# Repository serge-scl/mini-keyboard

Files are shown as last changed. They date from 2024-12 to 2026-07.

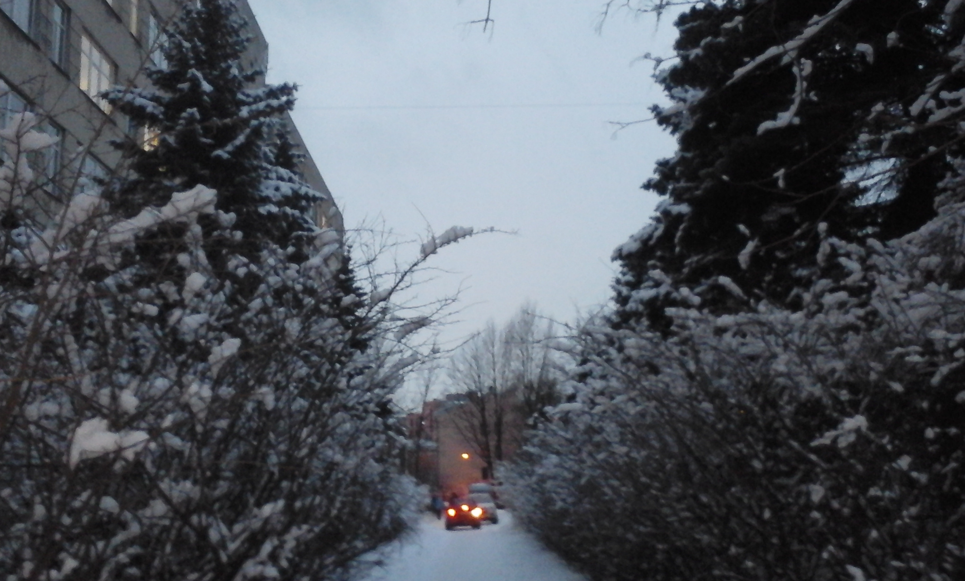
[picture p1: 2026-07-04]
media/winta_light.jpg

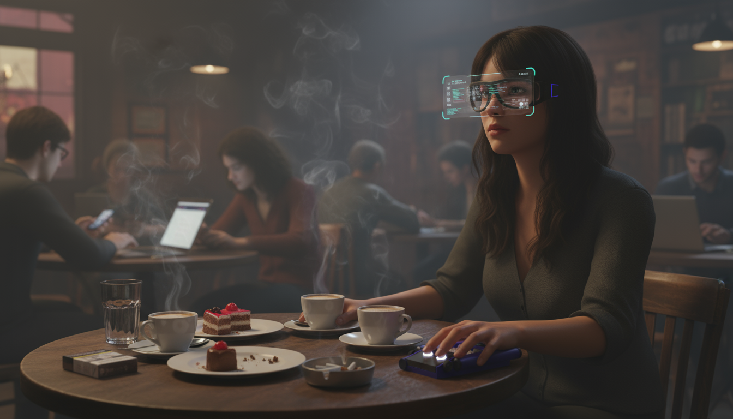
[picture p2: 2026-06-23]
media/cafe.png

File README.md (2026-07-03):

# Mouse Keyboard Pyramids (MKP)

Hybrid mouse + keyboard using pyramid-shaped touch/tilt keys. MKP combines capacitive touch, tilt sensing, and small-form HID firmware to provide an alternative input device for typing and pointing.

## Features
- Pyramid-shaped keys: touch shows cursor location; tilt selects symbols/directions.
- Position sensing: MPR121 capacitive touch controller (per-pyramid address).
- Tilt sensing: magnet-mounted mesh + Hall sensors detect X/Y tilt.
- Keyboard: 5×3 matrix (with diodes) + two dedicated joystick inputs.
- Pointing: optional optical sensor (PMW3360) and two side scroll wheels (one per side).
- Modular hardware: removable side modules with 4×AA battery holders and PCBs; LED backlight PCB under keyboard.
- Assembly designed for minimal tools; partly tool-free disassembly.
- Wireless option: Raspberry Pi Pico (or Pico W for Wi‑Fi); CircuitPython with Adafruit libraries and HID support.

## Software & Files
- CircuitPython code and example text editor included in repo root (Python).
- FreeCAD (part/assembly) models and KiCad schematics/PCB in respective folders.
- Datasheet folder contains BOM, diagrams, and images.

## License
CC‑BY‑4.0

## Contact
Serge Sokolov — sergesclv@gmail.com / sergesclv3@protonmail.com

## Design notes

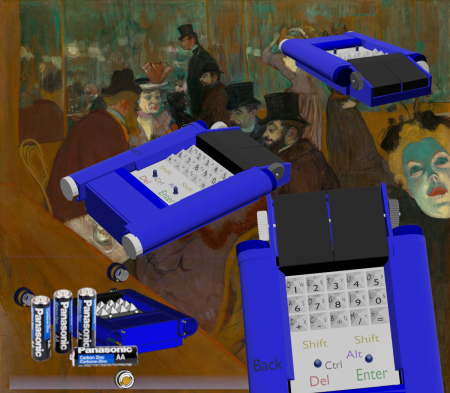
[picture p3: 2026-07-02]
media/mkps_290626.png

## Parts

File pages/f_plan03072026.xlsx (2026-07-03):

 |  |  | Financial plan
 |  | ncludes sponsorship support for open source, non-profit development
 |  | since the plan also includes starting a company
 |  | Funds from sponsorship support will be used for travel, accommodation, and opening the company itself in a location where this is possible.
 |  |  | final amounts
 |  | total investment amount |  |  | $ | 420000
 |  | planned batch of devices |  |  | unit | 100000
 |  | total sales revenue |  |  | $ | 19900000
 |  | margin |  |  | $ | 1990000
 |  | I apologize for my literary style (but I am also offering something that is the same writing instrument as a pen, ballpoint pen, or typewriter).
 |  | The batch of 100,000 pieces considered here is naturally not the entire consumer niche of my device.
 |  | This is only the first story about the initial stage of all the work. And it has its own separate plot.
 |  | This is an assumption, and like any assumption it must end where everything seems reliable for now.
 |  |  | The stage of burning financial resources.
 | support from sponsors |  |  | 6500 | 8100
 |  |  |  |  | Revenue item $ | Expense item $ | $ unit | quantity | time
 |  | flight tickets |  |  |  | 1200 | 600 | 2
 |  | accommodation |  |  |  | 1400 | 700 | 2 | 7 | days
 |  | daily expenses |  |  |  | 2000 | 1000 | 2 | 7 | days
 |  | open a company
 |  |  | LLC |  |  | 1900
 |  |  | C-Corp |  |  | 3500
 | investments in newly opened company
 |  |  |  | LLC | 413500
 |  |  |  | C-Corp | 411900
 |  | company office |  |  |  | 61200 | 1700 | 4 | 9 | months
 |  | equipment |  |  |  | 40000 | 10000 | 4
 |  | pre-production units of the device |  |  |  | 57820 | 5782 | 10
 | hiring |  |  |  |  |  | salary | vacancies
 |  | designer |  |  |  | 90000 | 60000 | 2 | 9 | months
 |  | PR menager |  |  |  | 15000 | 60000 | 1 | 3 | months
 |  | electronics development |  |  |  | 30000 | 60000 | 1 | 6 | months
 |  | firmware creation |  |  |  | 30000 | 60000 | 1 | 6 | months
 |  | sum |  |  |  |  |  | 5
 | website creation
 |  | server |  |  |  | 2000
 |  | domain registration |  |  |  | 20
 |  | web development |  |  |  | 10000
 |  | website administration |  |  |  | 30000
 |  | text editor project |  |  |  | 5000
 |  | sum |  |  |  | 371040
 |  | balance on accounts
 |  |  |  | LLC | 42460
 |  |  |  | C-Corp | 40860
 | cost estimate
 |  | assembly operation |  |  | quantity | seconds | just seconds
 |  |  | 1 |  | 6 | 10 | 60
 |  |  | 2 |  | 17 | 10 | 170
 |  |  | 3 |  | 17 | 15 | 255
 |  |  | 4 |  | 3 | 10 | 30
 |  |  | 5 |  | 3 | 10 | 30
 |  |  | 6 |  | 8 | 15 | 120
 |  |  | 7 |  | 3 | 15 | 45
 |  |  | 8 |  | 2 | 10 | 20
 |  |  | 9 |  | 2 | 10 | 20
 |  |  | 10 |  | 1 | 15 | 15
 |  |  | 11 |  | 1 | 10 | 10
 |  |  | 12 |  | 2 | 10 | 20
 |  |  | 13 |  | 2 | 15 | 30
 |  |  | 14 |  | 1 | 10 | 10
 |  |  | 15 |  | 18 | 10 | 180
 |  |  | 16 |  | 6 | 10 | 60
 |  |  | 17 |  | 1 | 10 | 10
 |  |  | 18 |  | 5 | 10 | 50
 |  |  | 19 |  | 4 | 10 | 40
 |  |  | 20 |  | 1 | 15 | 15
 |  |  | 21 |  | 4 | 10 | 40
 |  |  |  |  | time
 | working days per year |  |  |  | 249
 | hours in a working day |  |  |  | 8
 | hours per assembly day |  |  |  | 5
 | working minutes per year |  |  |  | 119520
 | assembly minutes per year |  |  |  | 74700
 |  | assembly of one device
 | seconds |  |  |  | 1230
 | minutes |  |  |  | 20.5
 | hours |  |  |  | 0.3416666667
 | daily norm |  |  |  | 15
 | assembly of the entire batch of devices
 | Man-hours |  |  |  | 3417
 | man-days |  |  |  | 683
 | In the business plan, I explained in more detail why I only consider five hours a day to be allocated to assembly work.
 | In short, the remaining three hours are a preparatory period.
 | period of work with the participation of all teams of assemblers
 |  |  |  |  | 68.3
 |  |  | price |  | $
 | rent of industrial premises |  |  |  | 4320
 | electricity bills |  |  |  | 266400
 | price of conditional working minute of assembler |  |  |  | 0.6157965194
 | cost of assembly of one product
 | cost of the assembler's time |  |  |  | 13
 | other salaries, rent and electricity |  |  |  | 17
 | overhead costs 100% |  |  |  | 30
 | supply of plastic injection molding components |  |  |  | 104
 | springs and fasteners |  |  |  | 2
 | motherboard |  |  |  | 12
 | additional electronic components |  |  |  | 5
 | trading platform commission |  |  |  | 9.95 | 5 | %
 | transaction commission |  |  |  | 5.97 | 3 | %
 | sum |  |  |  | 198.92
 |  |  | Crowdfunding |  | Revenue item $ | Expense item $ | $ unit | quantity
 | creating an advertising video |  |  |  |  | 4000
 | other advertising and promotion costs |  |  |  |  | 10000
 | time |  |  |  |  |  |  | 2 | month
 | required funds and quantity to start work |  |  |  | 1990000 |  | 199 | 10000
 | hiring the required employees
 |  | Head of Supply Department |  |  |  | 120000 | 120000 | 1
 |  | production manager |  |  |  | 120000 | 120000 | 1
 |  | assembly line workers |  | random |  | 460000 | 46000 | 10
 |  | repairmans |  |  |  | 60000 | 30000 | 2
 |  | tester |  |  |  | 50000 | 50000 | 1
 |  |  |  |  |  |  |  | 5
 |  | pre-launch costs
 | prepayment for ordering press molds |  |  |  |  | 360000 | 60000 | 20 | 0.3
 | advance payment for the first batch of parts |  |  |  |  | 312000 | 104 | 10000 | 0.3
 | electronic components |  |  |  |  | 170000 | 17 | 10000 | 1
 | payment for initial production downtime |  |  | day
 |  |  |  | 1 |  | 4469
 |  |  | week | 5 |  | 22345
 |  |  | month | 22 |  | 98318
 |  |  | possible term | 50 |  | 223450
 |  |  |  |  |  | 1190582
 |  |  |  | Start Working
 | workers | daily profit |  | break-even point
 | in assembly | $ |  | weeks | with downtime
 | 9 | 3150 |  | 24 | 34
 | 10 | 3880 |  | 19.6 | 29.8
 | 11 | 4663 |  | 16.2 | 26.6
 | 12 | 5446 |  | 14 | 24.6
 | 13 | 6177 |  | 12.2 | 23
 | 14 | 6960 |  | 10.8 | 21.8
 | 15 | 7743 |  | 9.8 | 21
 | 16 | 8473 |  | 9 | 20.4
 | 17 | 9256 |  | 8.2 | 19.8
 | 18 | 9987 |  | 7.6 | 19.4
 | 19 | 10770 |  | 7 | 19
 | 20 | 11552 |  | 6.6 | 18.8
 | 21 | 12283 |  | 6.2 | 18.6
 | 22 | 13066 |  | 5.8 | 18.4
 | 23 | 13849 |  | 5.4 | 18.2
 | 24 | 14579 |  | 5.2 | 18.2
 | 25 | 15362 |  | 5 | 18.2
 | 26 | 16093 |  | 4.8 | 18.2
 | 27 | 16876 |  | 4.4 | 18
 | 28 | 17659 |  | 4.2 | 18
 | 29 | 18389 |  | 4.2 | 18.2
 | The advantage of a large team of assemblers seems obvious
 | if we don't have to take time delays into account
 | These delays are related to the hiring of new employees and their training
 | I don't think I'll be able to hire more than one new employee a day
 | When I added this amendment to the general downtime period, I got the result that there were no advantages in terms of time
 | Therefore, a large team is not a good solution to the problem of deadlines and product development.
 |  | total number | all time from rise of funds |  | Rise+work | working
 |  | employees | year | month | months | months
 |  | 10
 |  | 19 | 1.38 | 16.5 | 10.5 | 8.5
 |  | 20 | 1.29 | 15.45 | 9.45 | 7.45
 |  | 21 | 1.22 | 14.65 | 8.65 | 6.65
 |  | 22 | 1.18 | 14.15 | 8.15 | 6.15
 |  | 23 | 1.15 | 13.75 | 7.75 | 5.75
 |  | 14 | 1.12 | 13.45 | 7.45 | 5.45
 |  | 25 | 1.1 | 13.25 | 7.25 | 5.25
 |  | 26 | 1.09 | 13.1 | 7.1 | 5.1
 |  | 17 | 1.08 | 12.95 | 6.95 | 4.95
 |  | 28 | 1.07 | 12.85 | 6.85 | 4.85
 |  | 29 | 1.06 | 12.7 | 6.75 | 4.75
 |  | 30 | 1.06 | 12.7 | 6.7 | 4.7
 |  | 31 | 1.05 | 12.65 | 6.65 | 4.65
 |  | 32 | 1.05 | 12.6 | 6.6 | 4.6
 |  | 33 | 1.05 | 12.55 | 6.55 | 4.55
 |  | 34 | 1.05 | 12.55 | 6.55 | 4.55
 |  | 35 | 1.05 | 12.55 | 6.55 | 4.55
 |  | 36 | 1.05 | 12.55 | 6.55 | 4.55
 |  | 37 | 1.04 | 12.5 | 6.5 | 4.5
 |  | 38 | 1.04 | 12.5 | 6.5 | 4.5
 |  | 39 | 1.05 | 12.55 | 6.55 | 4.55
 |  |  | Timeline
 |  | First year
 | first quarter of the first year |  |  | second quarter of the first year |  |  | third quarter of the first year |  |  | fourth quarter of the first year
 | 1 month | 2 month | 3 month | 4 month | 5 month | 6 month | 7 month | 8 month | 9 month | 10 month | 11 month | 12 month
$ monthly | -8100 | -101200 | -62820 | -17020 | -24167 | -38167 | -24167 | -558487 | -53334 | -62917 | 598922 | 638529
$ total | -8100 | -109300 | -172120 | -189140 | -213307 | -251474 | -275641 | -834128 | -887462 | -950379 | -351457 | 287072
units of devices manufactured |  |  | 10 | 0 | 0 | 0 | 0 | 0 | 0 | 0 | 5175 | 6600
$ with | 411900 | -101200 | -62820 | -17020 | -24167 | -38167 | 1965833 | -558487 | -53334 | -62917 | -85117 | -85117
invest | 411900 | 310700 | 247880 | 230860 | 206693 | 168526 | 2134359 | 1575872 | 1522538 | 1459621 | 1374504 | 1289387
 | Serge Sokolov
 | app 18
 | 23 Lakhtinska
 | St. Petersburg 197136
 | Russia
 | Ph +79522711742
 | sergesclv@gmail.com
 | sergesclv3@protonmail.com
 | https://ru.linkedin.com/in/serge-sokolov-abb5319
 | https://x.com/SeregeSokolov
 | https://github.com/serge-scl/mini-keyboard
 | https://www.facebook.com/sergesclv/
 | https://maker.pro/raspberry-pi/projects/mouse-keyboard-pyramids

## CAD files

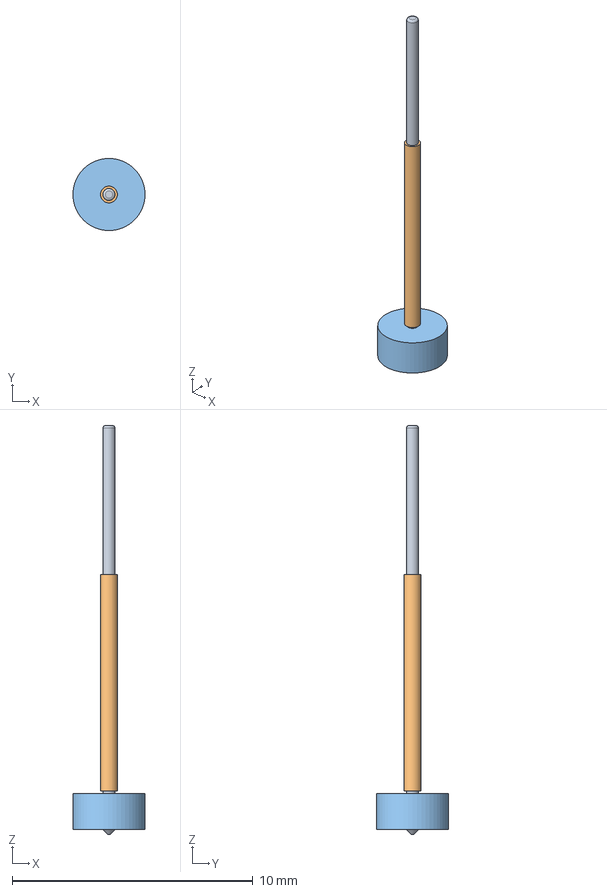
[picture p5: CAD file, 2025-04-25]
assembly/main_rod_arm.FCStd
3.00 x 3.00 x 17.0 mm
tilt_rod_core_001
rod shell top_001
rod_shell_foot_001

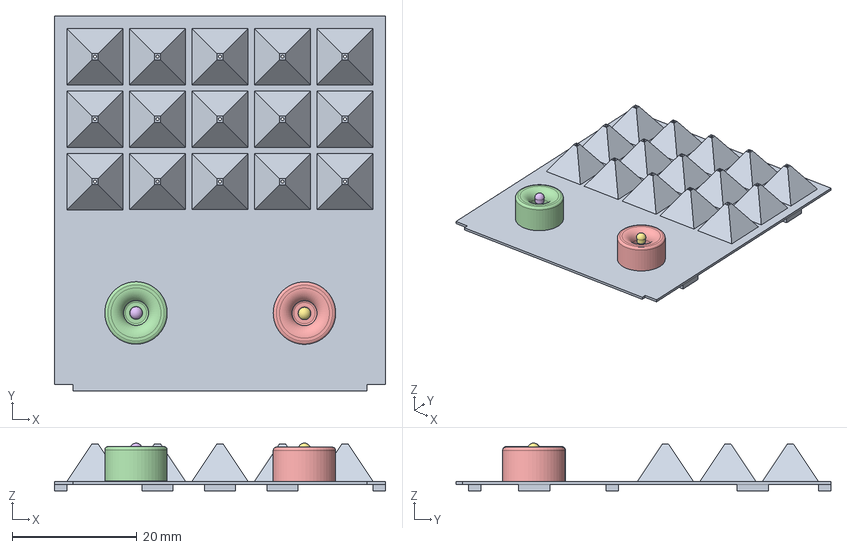
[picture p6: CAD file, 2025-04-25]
assembly/pyramids_asm.FCStd
53.0 x 60.0 x 7.65 mm
pyramids_001
steel_ring_001
steel_ring_002
Joystick_001
Joystick_002
boll_tilt_001
boll_tilt_002

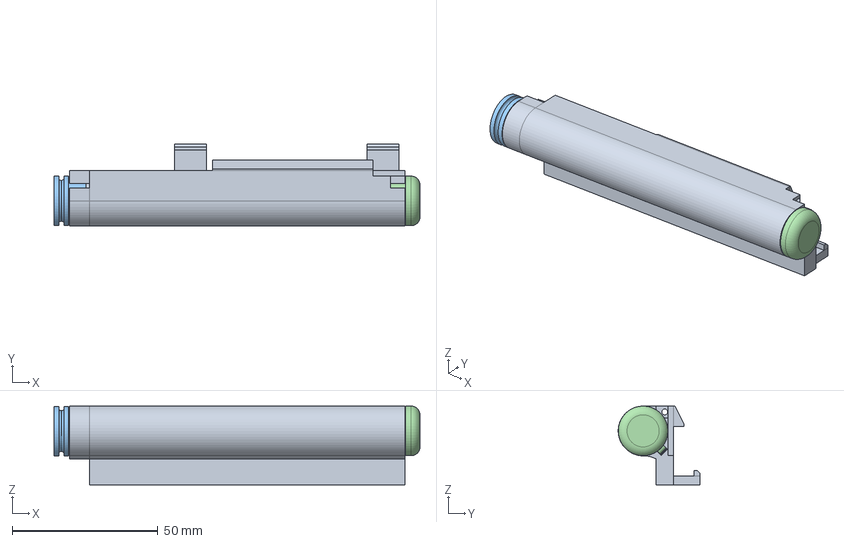
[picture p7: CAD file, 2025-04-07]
assembly/battery_wall_right_asm.FCStd
125.4 x 28.0 x 27.0 mm
battery_wall_right_001
conn_btr_asm_001
plug_back_conn_001
plug_front_conn_001

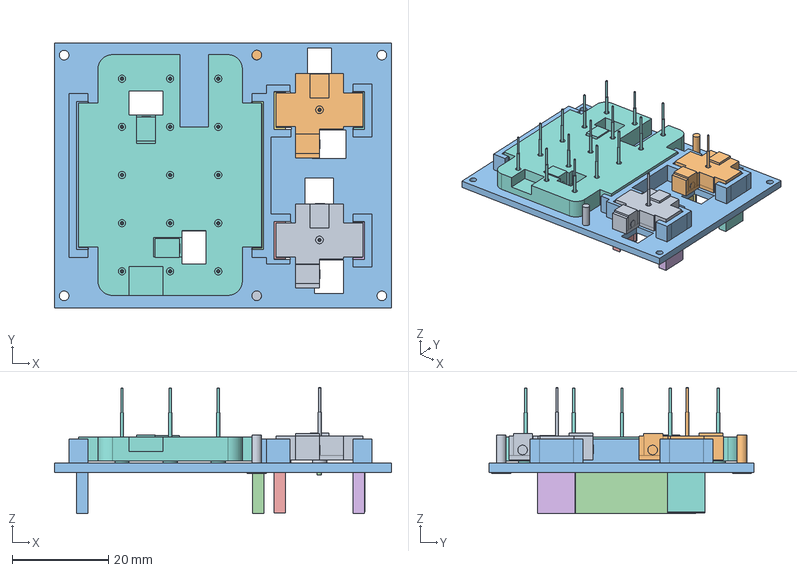
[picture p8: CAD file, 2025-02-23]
assembly/main module.FCStd
70.0 x 55.0 x 26.2 mm
mov_joystick_block_001
mov_joystick_block_002
touch_bottom2_001
pewter_foot1_002
pewter_foot1_003
pewter_foot2_002
pewter_foot2_003
mov_kb_block_002
fix_m_001
fix_m_002
kb_set_001
kb_set_002
joyst_set_001
joyst_set_002
joyst_set_003
joyst_set_004

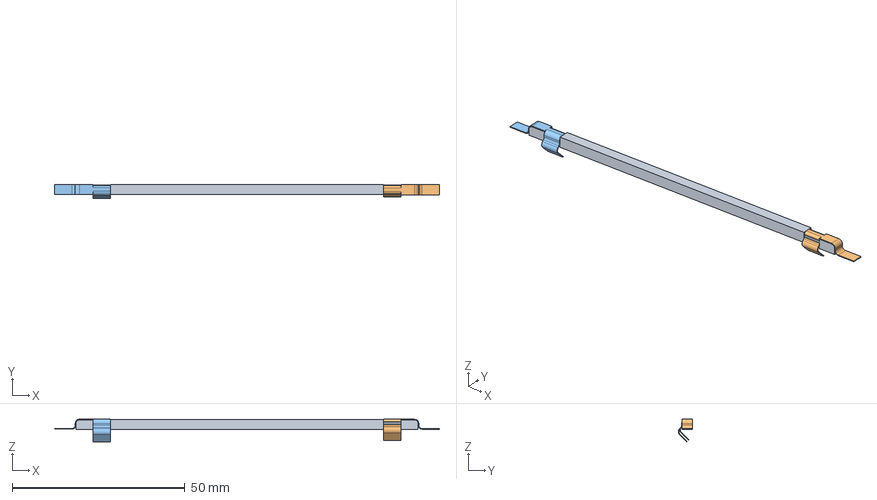
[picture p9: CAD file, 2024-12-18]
assembly/conn_btr_asm.FCStd
111.4 x 4.20 x 6.58 mm
wall_conn_btr_001
pin_conn_btr_001
pin_conn_btr2_001

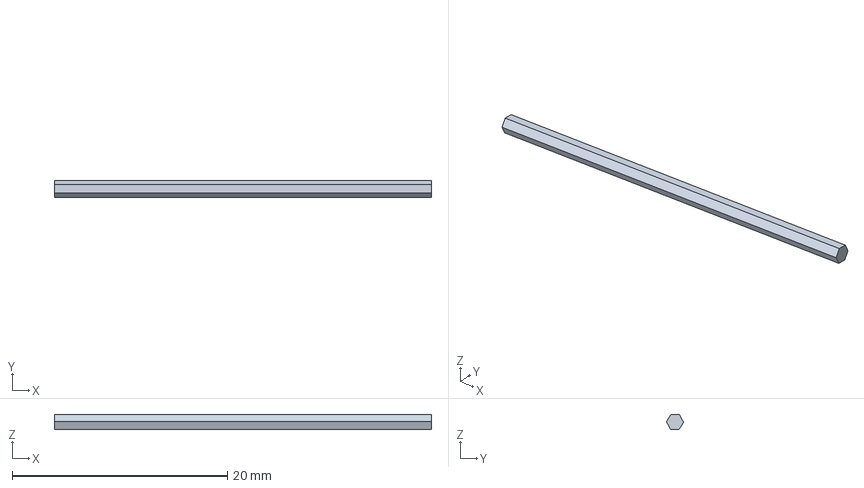
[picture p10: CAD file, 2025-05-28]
part/mouse_wheel_axis.FCStd
35.0 x 1.60 x 1.42 mm

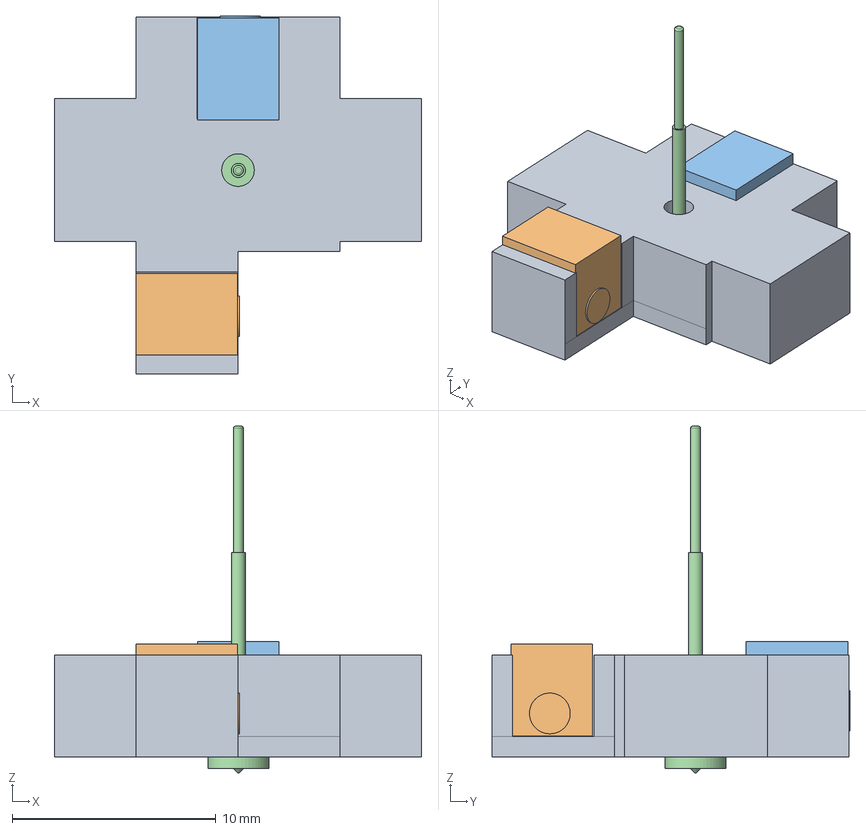
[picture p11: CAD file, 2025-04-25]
assembly/mov_joystick_block.FCStd
18.0 x 17.6 x 17.0 mm
sliding_cell_001
magnet_with_holder_001
magnet_with_holder_002
main_rod_arm_001

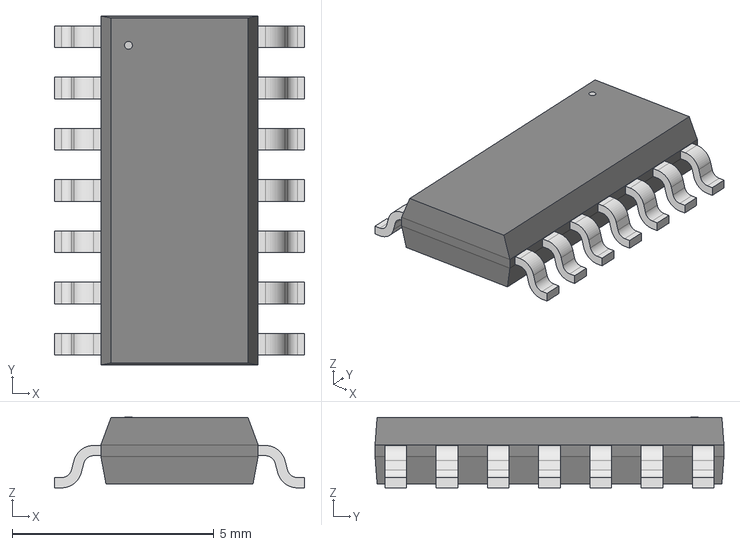
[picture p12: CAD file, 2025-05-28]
part/SOIC14_SL_MCH.step
6.20 x 8.65 x 1.75 mm

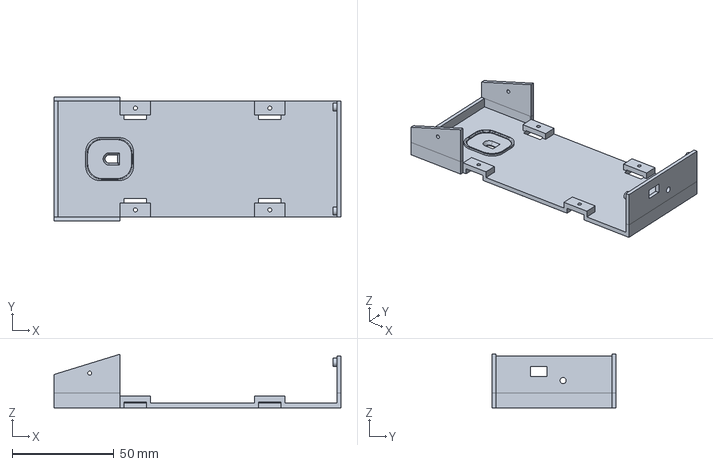
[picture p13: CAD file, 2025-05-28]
part/bottom.FCStd
141.0 x 61.0 x 26.4 mm

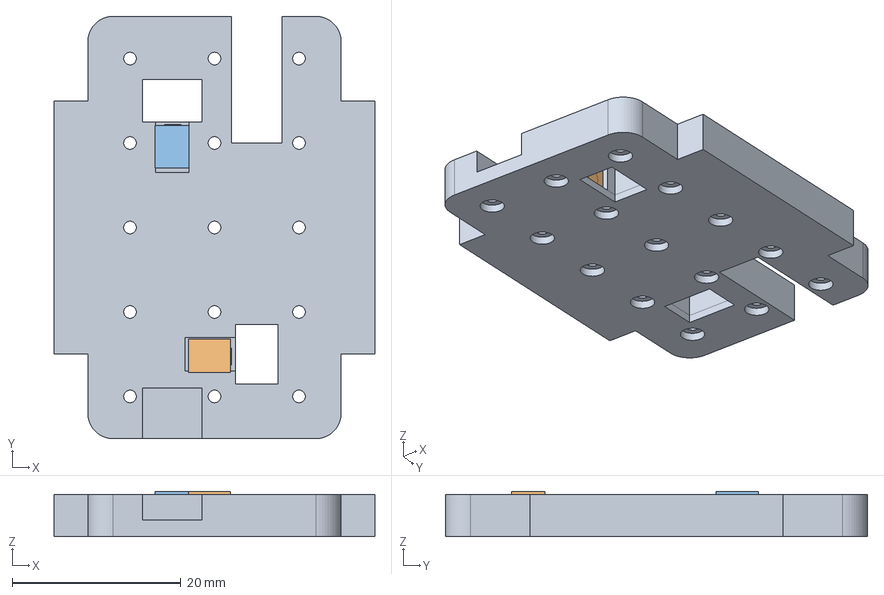
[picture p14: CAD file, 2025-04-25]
assembly/mov_kb_block.FCStd
38.0 x 50.0 x 5.37 mm
sliding_mesh_001
magnet_with_holder_001
magnet_with_holder_002

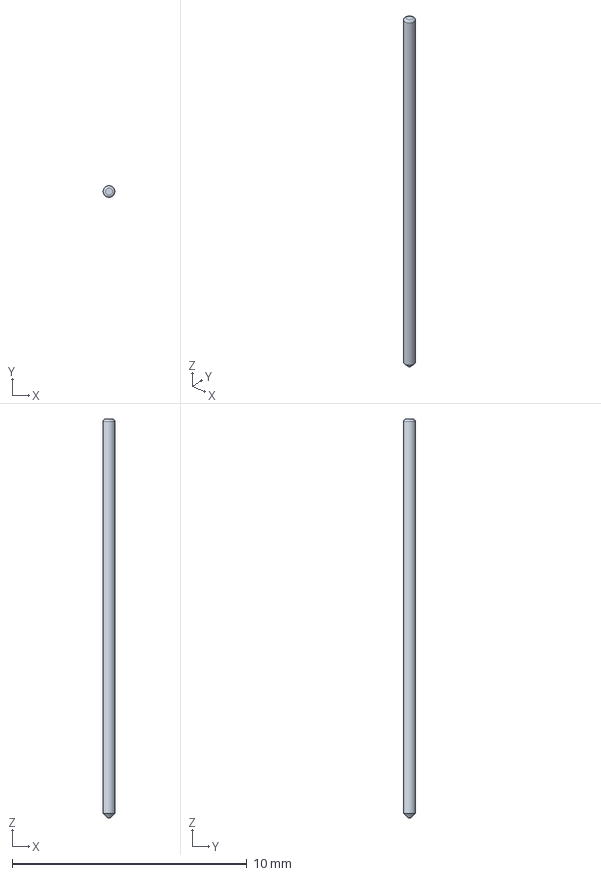
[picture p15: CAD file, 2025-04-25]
part/tilt_rod_core.FCStd
0.5 x 0.5 x 17.0 mm

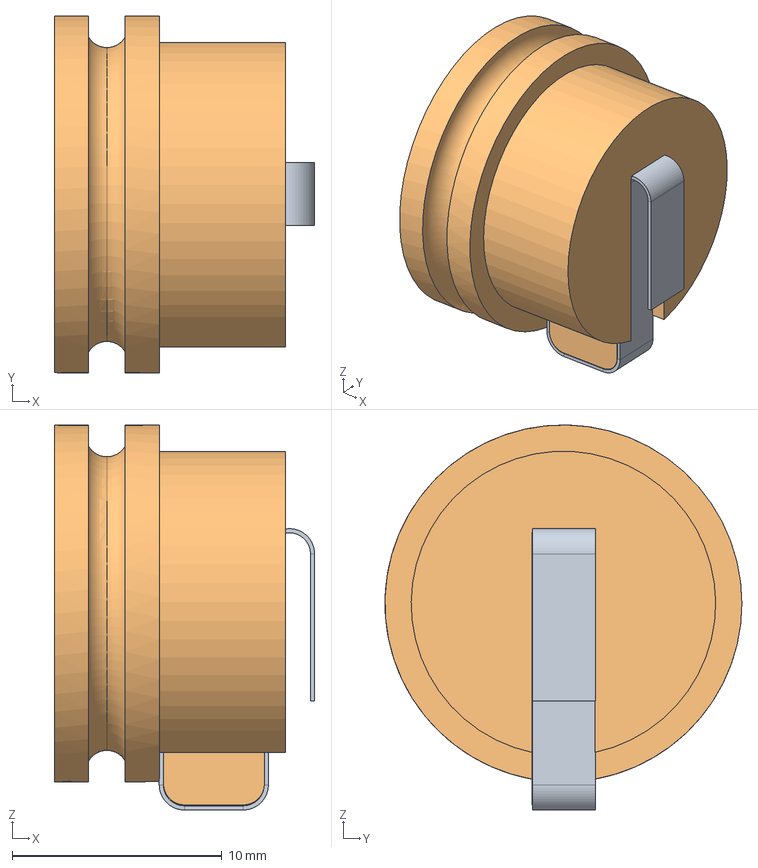
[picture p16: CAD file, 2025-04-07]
assembly/plug_back_conn.FCStd
12.4 x 17.0 x 18.3 mm
batr_conn_pls_001
plug_back_001

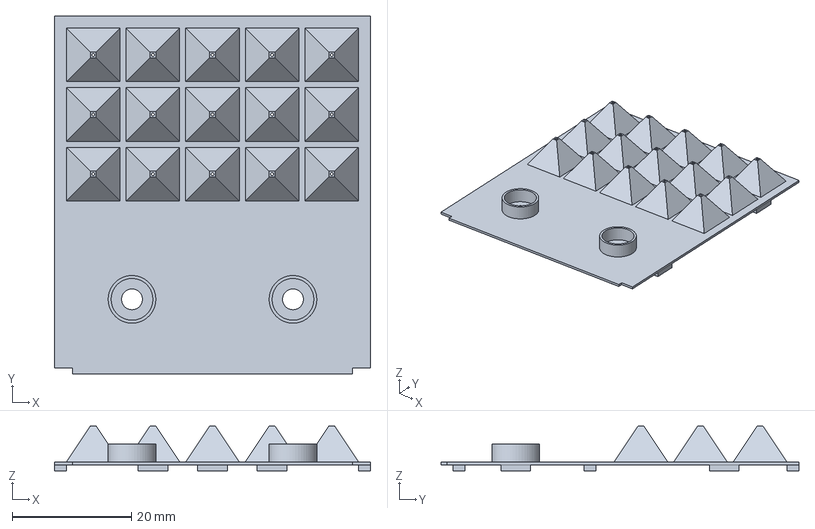
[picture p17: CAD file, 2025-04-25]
part/pyramids.FCStd
53.0 x 60.0 x 7.50 mm

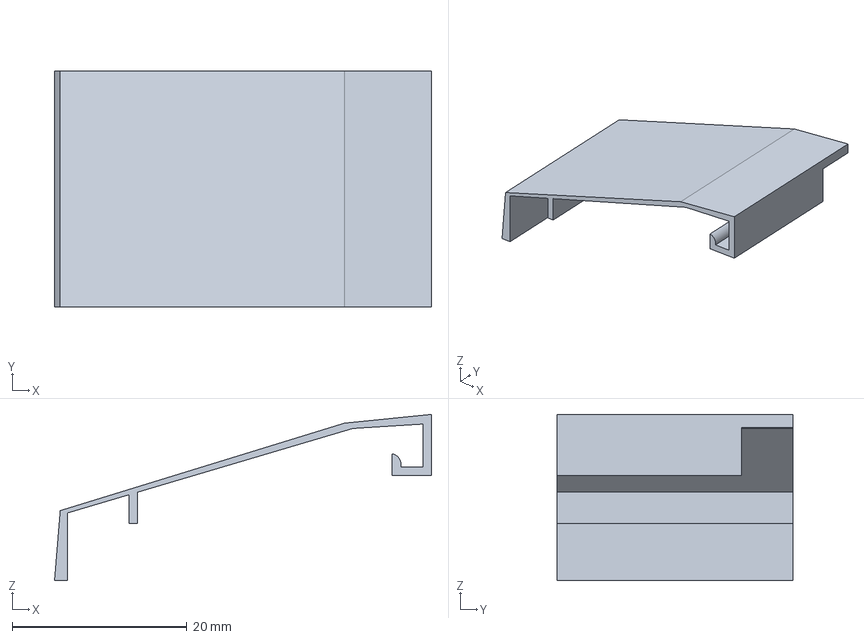
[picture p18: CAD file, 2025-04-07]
part/mouse_button_right.FCStd
43.1 x 27.0 x 19.0 mm

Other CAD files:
assembly/battery_wall_left_asm.FCStd
part/wheell_z2_2.FCStd
assembly/plug_front_conn.FCStd
part/steel_ring.FCStd
assembly/Raspberry_pi_Pico.FCStd
assembly/back_cover_stock.FCStd
assembly/button_mechanism.FCStd
assembly/magnet_with_holder.FCStd
assembly/mouse_keyboard_pyramids.FCStd
assembly/mouse_keyboard_pyramids2.FCStd
assembly/tch_btm_conn.FCStd
part/ battery_wall_right.FCStd
part/BF020-02-A-B-0600-0100-N-G.stp
part/BF020-10-A-B-0300-0200-N-G.stp
part/BF050-04-A-B-0600-0100-N-G.stp
part/BF086-02-A-0300-N-D.stp
part/BF088-10-A-L-D.stp
part/BF110-04-A-G.stp
part/CP_EIA-1608-08_AVX-J.step
part/CP_EIA-3216-12_Kemet-S.step
part/CP_EIA-3528-12_Kemet-T.step
part/D_SOD-123F.step
part/D_SOD-523.step
part/Joystick.FCStd
part/LED 2835.stp
part/LED_1206_3216Metric_Castellated.step
part/LED_D1.8mm_W3.3mm_H2.4mm.step
part/RC0402N_PAN.step
part/R_0402_1005Metric.step
part/R_0603_1608Metric.step
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

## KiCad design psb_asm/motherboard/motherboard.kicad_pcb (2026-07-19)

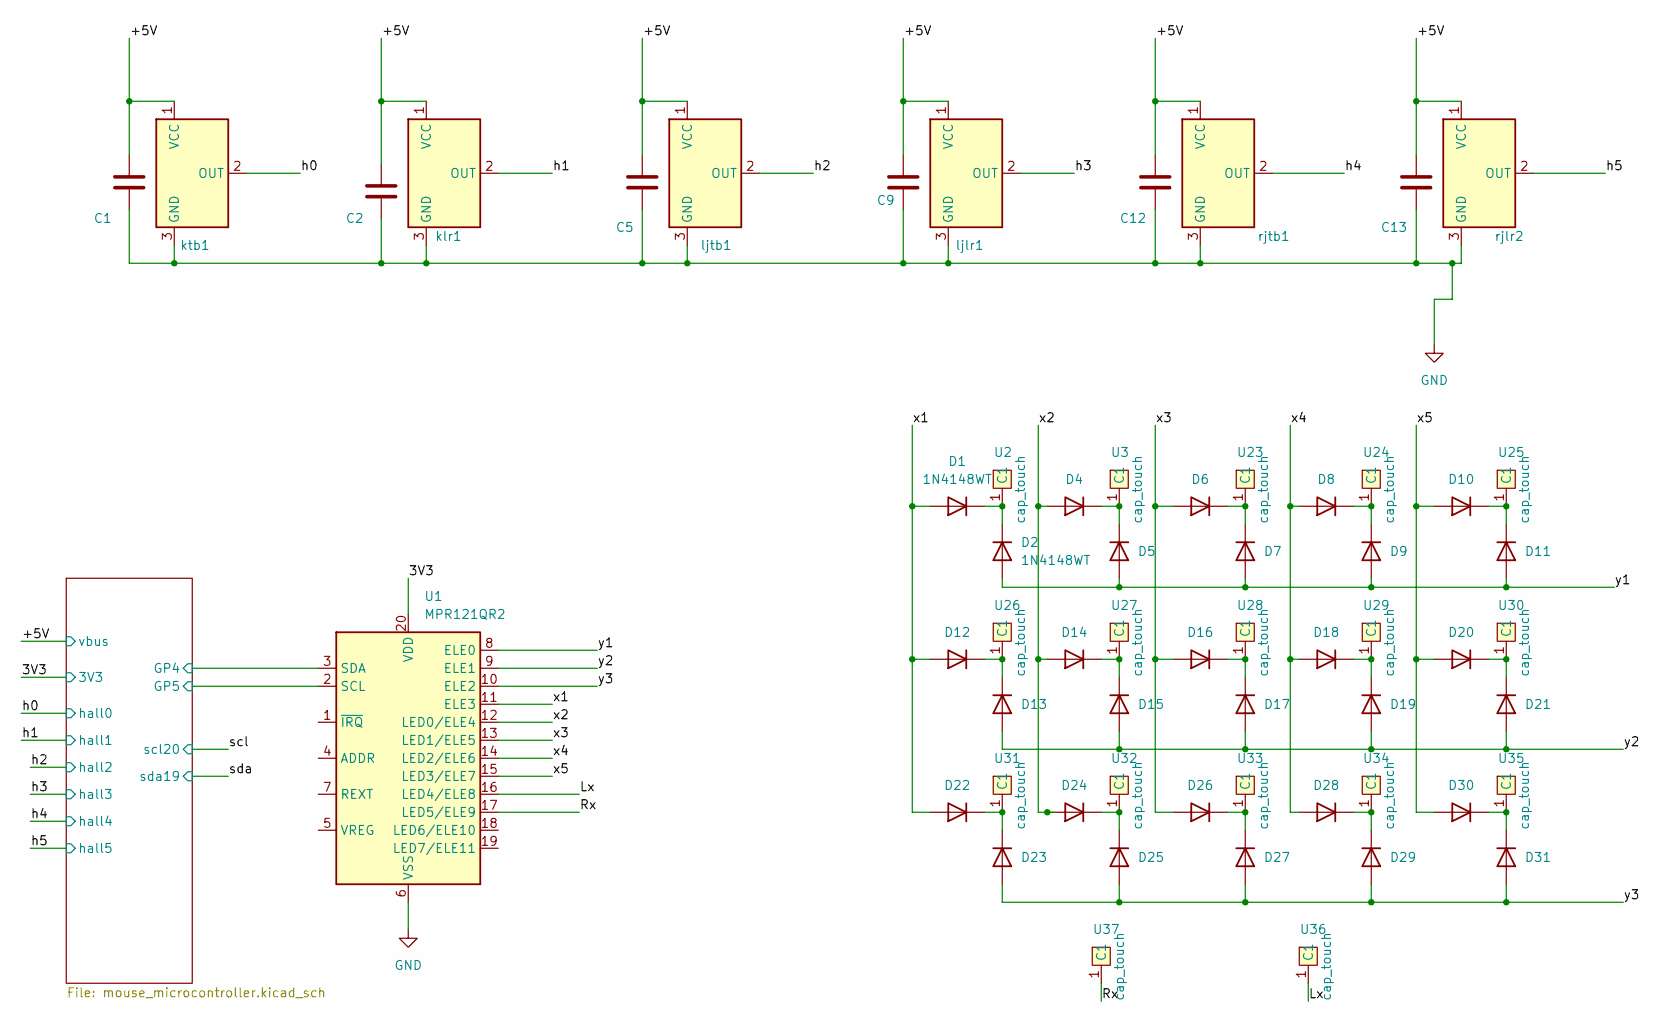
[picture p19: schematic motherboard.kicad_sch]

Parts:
C1, C2, C5, C9, C12, C13: 0.01uf; CP_EIA-1608-08_AVX-J_Pad1.25x1.05mm_HandSolder
D1, D2, D4, D5, D6, D7, D8, D9, D10, D11, D12, D13, D14, D15, D16, D17, D18, D19, D20, D21, D22, D23, D24, D25, D26, D27, D28, D29, D30, D31: 1N4148WT; D_SOD-523
U1: MPR121QR2; UQFN-20_3x3mm_P0.4mm
U2, U3, U23, U24, U25, U26, U27, U28, U29, U30, U31, U32, U33, U34, U35, U36, U37: cap_touch
klr1: TO-92S
ktb1: TO-92S
ljlr1: DRV505; TO-92S
ljtb1: DRV505; TO-92S
rjlr2: DRV505; TO-92S
rjtb1: DRV505; TO-92S

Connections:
/3V3: U1.20 (VDD); also elsewhere on the board
/+5V: C1.1, C2.1, C5.1, C9.1, C12.1, C13.1, klr1.1 (VCC), ktb1.1 (VCC), ljlr1.1 (VCC), ljtb1.1 (VCC), rjlr2.1 (VCC), rjtb1.1 (VCC); also elsewhere on the board
/Lx: U1.16 (LED4/ELE8), U36.1 (C1)
/Mouse_and_microcontroller/GP4: U1.3 (SDA); also elsewhere on the board
/Mouse_and_microcontroller/GP5: U1.2 (SCL); also elsewhere on the board
/Rx: U1.17 (LED5/ELE9), U37.1 (C1)
/h0: ktb1.2 (OUT); also elsewhere on the board
/h1: klr1.2 (OUT); also elsewhere on the board
/h2: ljtb1.2 (OUT); also elsewhere on the board
/h3: ljlr1.2 (OUT); also elsewhere on the board
/h4: rjtb1.2 (OUT); also elsewhere on the board
/h5: rjlr2.2 (OUT); also elsewhere on the board
/x1: D1.2 (A), D12.2 (A), D22.2 (A), U1.11 (ELE3)
/x2: D4.2 (A), D14.2 (A), D24.2 (A), U1.12 (LED0/ELE4)
/x3: D6.2 (A), D16.2 (A), D26.2 (A), U1.13 (LED1/ELE5)
/x4: D8.2 (A), D18.2 (A), D28.2 (A), U1.14 (LED2/ELE6)
/x5: D10.2 (A), D20.2 (A), D30.2 (A), U1.15 (LED3/ELE7)
/y1: D2.2 (A), D5.2 (A), D7.2 (A), D9.2 (A), D11.2 (A), U1.8 (ELE0)
/y2: D13.2 (A), D15.2 (A), D17.2 (A), D19.2 (A), D21.2 (A), U1.9 (ELE1)
/y3: D23.2 (A), D25.2 (A), D27.2 (A), D29.2 (A), D31.2 (A), U1.10 (ELE2)
GND: C1.2, C2.2, C5.2, C9.2, C12.2, C13.2, U1.6 (VSS), klr1.3 (GND), ktb1.3 (GND), ljlr1.3 (GND), ljtb1.3 (GND), rjlr2.3 (GND), rjtb1.3 (GND); also elsewhere on the board
unnamed: D1.1 (K), D2.1 (K), U2.1 (C1)
unnamed: D4.1 (K), D5.1 (K), U3.1 (C1)
unnamed: D6.1 (K), D7.1 (K), U23.1 (C1)
unnamed: D8.1 (K), D9.1 (K), U24.1 (C1)
unnamed: D10.1 (K), D11.1 (K), U25.1 (C1)
unnamed: D12.1 (K), D13.1 (K), U26.1 (C1)
unnamed: D14.1 (K), D15.1 (K), U27.1 (C1)
unnamed: D16.1 (K), D17.1 (K), U28.1 (C1)
unnamed: D18.1 (K), D19.1 (K), U29.1 (C1)
unnamed: D20.1 (K), D21.1 (K), U30.1 (C1)
unnamed: D22.1 (K), D23.1 (K), U31.1 (C1)
unnamed: D24.1 (K), D25.1 (K), U32.1 (C1)
unnamed: D26.1 (K), D27.1 (K), U33.1 (C1)
unnamed: D28.1 (K), D29.1 (K), U34.1 (C1)
unnamed: D30.1 (K), D31.1 (K), U35.1 (C1)

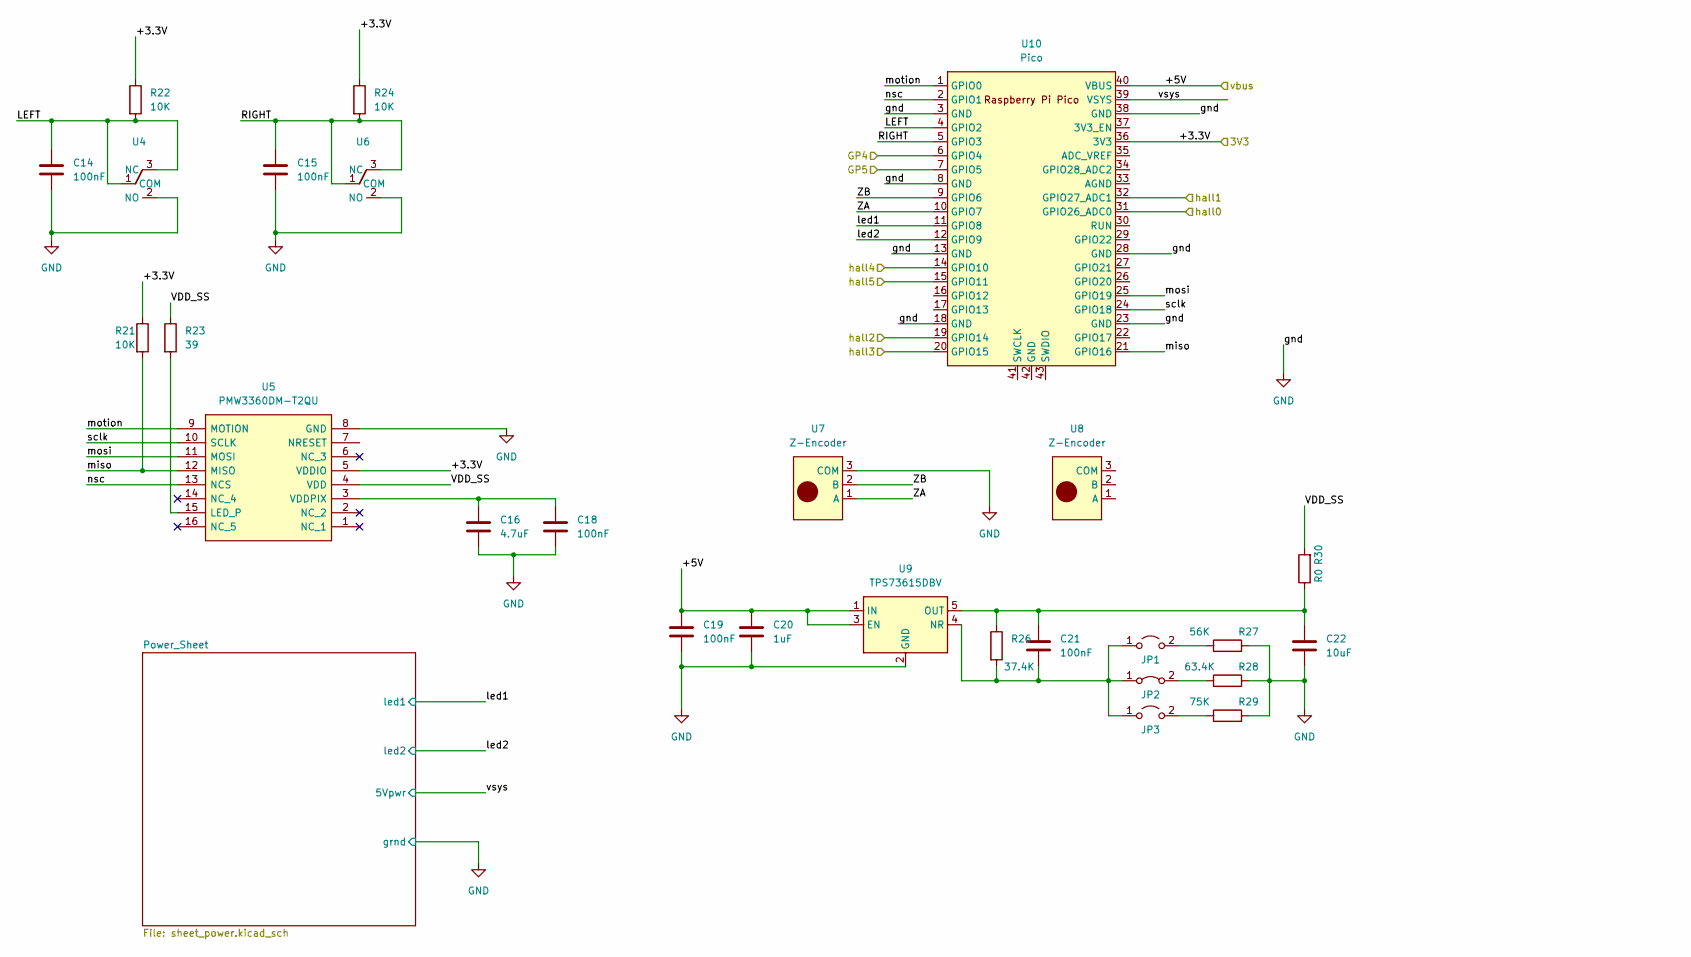
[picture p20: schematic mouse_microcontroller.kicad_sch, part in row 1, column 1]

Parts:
C14, C15, C19, C21: 100nF; CP_EIA-1608-08_AVX-J
C16: 4.7uF; CP_EIA-3216-12_Kemet-S_Pad1.58x1.35mm_HandSolder
C18: 100nF; CP_EIA-3216-12_Kemet-S_Pad1.58x1.35mm_HandSolder
C20: 1uF; CP_EIA-1608-08_AVX-J
C22: 10uF; CP_EIA-1608-08_AVX-J
JP1, JP3: Jumper_2_Open; jump_off
JP2: Jumper_2_Bridged; Jump_on
R21: 10K; R_0402_1005Metric_Pad0.72x0.64mm_HandSolder
R22, R24: 10K; R_0603_1608Metric_Pad0.98x0.95mm_HandSolder
R23: 39; R_0402_1005Metric_Pad0.72x0.64mm_HandSolder
R26: 37.4K; R_0603_1608Metric
R27: 56K; R_0603_1608Metric
R28: 63.4K; R_0603_1608Metric
R29: 75K; R_0603_1608Metric
R30: R0; R_0603_1608Metric
U4, U6: Switch; switch
U5: PMW3360DM-T2QU; PMW3360; Manufacturer_Part_Number PMW3360DM-T2QU
U7, U8: Z-Encoder
U9: TPS73615DBV; SOT-23-5
U10: Pico; RPi_Pico_SMD_TH

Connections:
/3V3: R21.1, R22.1, R24.1, U5.5 (VDDIO), U10.36 (3V3); also elsewhere on the board
/+5V: C19.1, C20.1, U9.1 (IN), U9.3 (EN), U10.40 (VBUS); also elsewhere on the board
/Mouse_and_microcontroller/GP4: U10.6 (GPIO4); also elsewhere on the board
/Mouse_and_microcontroller/GP5: U10.7 (GPIO5); also elsewhere on the board
/Mouse_and_microcontroller/LEFT: C14.1, R22.2, U4.1 (COM), U4.3 (NC), U10.4 (GPIO2)
/Mouse_and_microcontroller/RIGHT: C15.1, R24.2, U6.1 (COM), U6.3 (NC), U10.5 (GPIO3)
/Mouse_and_microcontroller/VDD_SS: R23.1, R30.2, U5.4 (VDD)
/Mouse_and_microcontroller/ZA: U7.1 (A), U10.10 (GPIO7)
/Mouse_and_microcontroller/ZB: U7.2 (B), U10.9 (GPIO6)
/Mouse_and_microcontroller/led1: U10.11 (GPIO8)
/Mouse_and_microcontroller/led2: U10.12 (GPIO9)
/Mouse_and_microcontroller/miso: R21.2, U5.12 (MISO), U10.21 (GPIO16)
/Mouse_and_microcontroller/mosi: U5.11 (MOSI), U10.25 (GPIO19)
/Mouse_and_microcontroller/motion: U5.9 (MOTION), U10.1 (GPIO0)
/Mouse_and_microcontroller/nsc: U5.13 (NCS), U10.2 (GPIO1)
/Mouse_and_microcontroller/sclk: U5.10 (SCLK), U10.24 (GPIO18)
/Mouse_and_microcontroller/vsys: U10.39 (VSYS)
/h0: U10.31 (GPIO26_ADC0); also elsewhere on the board
/h1: U10.32 (GPIO27_ADC1); also elsewhere on the board
/h2: U10.19 (GPIO14); also elsewhere on the board
/h3: U10.20 (GPIO15); also elsewhere on the board
/h4: U10.14 (GPIO10); also elsewhere on the board
/h5: U10.15 (GPIO11); also elsewhere on the board
GND: C14.2, C15.2, C16.2, C18.2, C19.2, C20.2, C22.2, R27.2, R28.2, R29.2, U4.2 (NO), U5.8 (GND), U6.2 (NO), U7.3 (COM), U9.2 (GND), U10.3 (GND), U10.8 (GND), U10.13 (GND), U10.18 (GND), U10.23 (GND), U10.28 (GND), U10.38 (GND); also elsewhere on the board
unnamed: C21.2, JP1.1 (A), JP2.1 (A), JP3.1 (A), R26.2, U9.4 (NR)
unnamed: JP1.2 (B), R27.1
unnamed: JP2.2 (B), R28.1
unnamed: JP3.2 (B), R29.1
unnamed: R23.2, U5.15 (LED_P)
unnamed: C16.1, C18.1, U5.3 (VDDPIX)
unnamed: C21.1, C22.1, R26.1, R30.1, U9.5 (OUT)

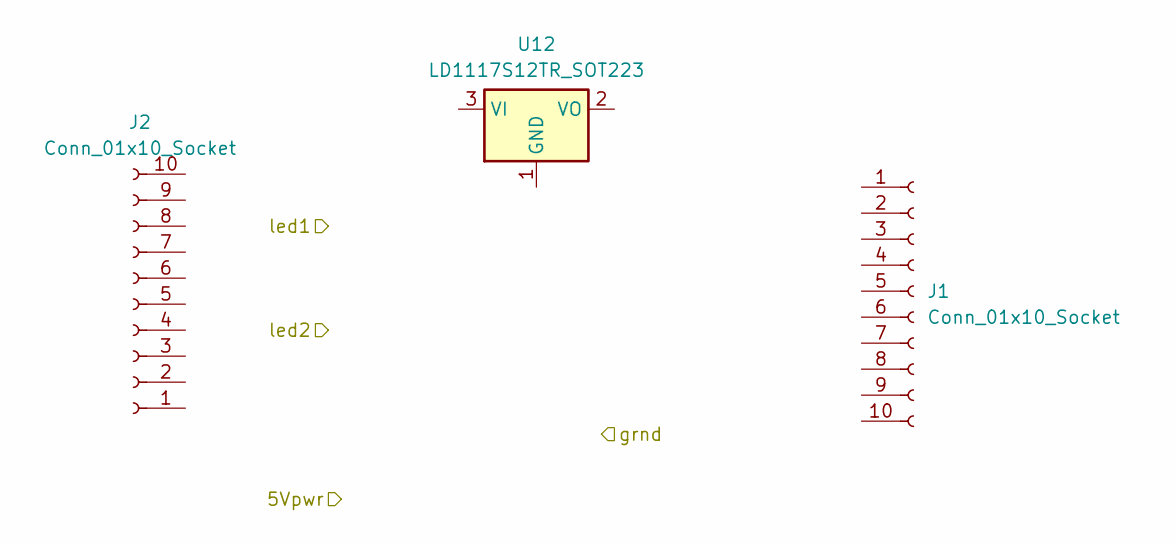
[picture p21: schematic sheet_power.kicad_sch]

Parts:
J1, J2: Conn_01x10_Socket; BF088
U12: LD1117S12TR_SOT223; SOT-223-3_TabPin2

Board: 2 copper layers, 93 parts (43 on the bottom side), 55 nets, no tracks yet.

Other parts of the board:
U13, U14, U15: PIC16F1455-I/SL; SOIC14_SL_MCH

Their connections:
/h1: U13.7 (RC3); also elsewhere on the board
/h2: U13.5 (RC5); also elsewhere on the board
/h3: U14.7 (RC3); also elsewhere on the board
/h4: U14.5 (RC5); also elsewhere on the board
/h5: U15.7 (RC3); also elsewhere on the board
/scl: U13.10 (RC0/ICSPDAT), U14.10 (RC0/ICSPDAT), U15.10 (RC0/ICSPDAT)
/sda: U13.9 (RC1/ICSPCLK), U14.9 (RC1/ICSPCLK), U15.9 (RC1/ICSPCLK)

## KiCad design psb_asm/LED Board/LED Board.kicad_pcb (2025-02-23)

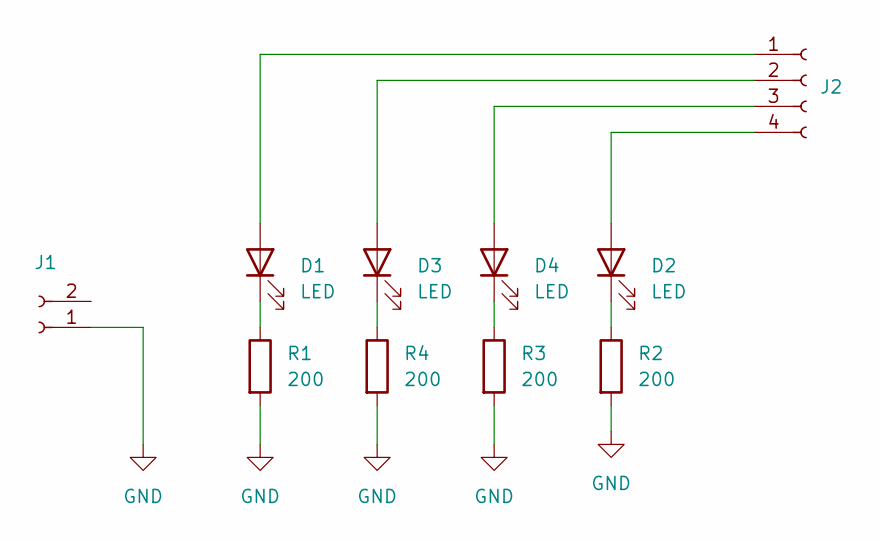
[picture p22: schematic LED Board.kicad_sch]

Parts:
D1, D2, D3, D4: LED; LED_PLCC_2835
J1: BF086
J2: PinSocket_2x02_P2.00mm_Horizontal
R1, R2, R3, R4: 200; RC0402N_PAN

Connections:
GND: J1.1, R1.2, R2.2, R3.2, R4.2
unnamed: D1.2 (A), J2.1
unnamed: D1.1 (K), R1.1
unnamed: D2.2 (A), J2.4
unnamed: D2.1 (K), R2.1
unnamed: D3.2 (A), J2.2
unnamed: D3.1 (K), R4.1
unnamed: D4.2 (A), J2.3
unnamed: D4.1 (K), R3.1

Board: 2 copper layers, 10 parts (6 on the bottom side), 9 nets, no tracks yet.

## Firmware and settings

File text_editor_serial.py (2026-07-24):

# mouse keyboard pyramids MKP
# Serge Sokolov
"""
Refactored version:
- ScrollTxt is a Frame that wraps a tk.Text with scrollbars (clean init, delegates methods).
- PyramidKeyboard is a reusable widget (tk.Frame) that renders a 3x5 pyramid keyboard
  and provides methods to set the active tip without recreating widgets.
- JoystickFrame is a small widget to show left/right joystick/modifier activity.
- Removed blocking time.sleep; replaced with non-blocking after().
- Highlights all 4 directional characters when a pyramid is selected.
"""

import tkinter as tk
from tkinter import filedialog


class Kb:
    tb_ch_e = ["'1", "\"2", "(3", "[4", "{5",
               "$6", "#7", "@8", ";9", "%0",
               ">+", "<-", "&*", ":/", "!="]
    rl_ch_e = ["QW", "ER", "TY", "UI", "OP",
               "AS", "DF", "GH", "JK", "L^",
               "ZX", "CV", "BN", "M?", ",."]

    joysticks = ["<-", "shift", "Del", "Ctrl", "Alt", "Shift", "Enter", "->"]

    ch_up_e = [x + y for x, y in zip(tb_ch_e, rl_ch_e)]
    rl_ch_lw_e = list(map(lambda x: x.lower(), rl_ch_e))
    ch_e = [x + y for x, y in zip(ch_up_e, rl_ch_lw_e)]

    font0 = 'Helvetica'
    font1 = 'Liberation Serif'
    bk_gr0 = 'LightCyan2'
    activ_bg = 'yellow3'
    akitv_text = 'red2'
    back_text = 'grey2'
    font_sz = 18

    tb_ch_ru = ["'1", "\"2", "(3", "[4", "{5",
                "Х6", "Ю7", "Э8", ";9", "%0",
                ">+", "<-", "&*", ":/", "!="]
    rl_ch_ru = ["ЙЦ", "УК", "ЕН", "ГШ", "ЩЗ",
                "ФЫ", "ВА", "ПР", "ОЛ", "ДЖ",
                "ЯЧ", "СМ", "ИТ", "ЬБ", ",."]

    ch_up_ru = [x + y for x, y in zip(tb_ch_ru, rl_ch_ru)]
    rl_ch_lw_ru = list(map(lambda x: x.lower(), rl_ch_ru))
    ch_ru = [x + y for x, y in zip(ch_up_ru, rl_ch_lw_ru)]


class ScrollTxt(tk.Frame):
    """A Frame containing a Text with vertical and horizontal scrollbars.
    Delegates text methods (get/insert/delete/...) to internal self.text via __getattr__.
    """

    def __init__(self, master=None, **kw):
        super().__init__(master)
        # Create scrollbars
        self.vbar = tk.Scrollbar(self, orient="vertical")
        self.hbar = tk.Scrollbar(self, orient="horizontal")
        # Create text widget with scroll commands connected
        text_kwargs = kw.copy()
        text_kwargs.setdefault('wrap', 'none')
        text_kwargs.update({'yscrollcommand': self.vbar.set, 'xscrollcommand': self.hbar.set})
        self.text = tk.Text(self, **text_kwargs)

        # Layout
        self.vbar.config(command=self.text.yview)
        self.hbar.config(command=self.text.xview)
        self.vbar.pack(side="right", fill="y")
        self.hbar.pack(side="bottom", fill="x")
        self.text.pack(side="left", fill="both", expand=True)

    def __getattr__(self, item):
        # Delegate unknown attributes to the internal Text widget (so users can call .get/.insert/.delete)
        try:
            return getattr(self.text, item)
        except AttributeError:
            raise AttributeError(f"'ScrollTxt' object has no attribute '{item}'")


class PyramidKeyboard(tk.Frame):
    """Reusable pyramid keyboard widget: rows x cols grid.
    Each cell has top/left/bottom/right labels and a center 'tip' label.
    Use set_active(index) to highlight all 4 directional chars + tip, or clear_active().
    """

    def __init__(self, master, rl_chars, tb_chars, rows=3, cols=5, **styles):
        super().__init__(master)
        self.rows = rows
        self.cols = cols
        self.rl_chars = rl_chars
        self.tb_chars = tb_chars
        self.styles = styles

        self.cell_frames = []
        self.cells = []  # list of dicts with label refs
        self._build_grid()

    def _safe_char(self, s, idx, default=""):
        return s[idx] if (s and len(s) > idx) else default

    def _build_grid(self):
        for r in range(self.rows):
            for c in range(self.cols):
                idx = r * self.cols + c
                frame = tk.Frame(self, bd=1, relief="flat")
                frame.grid(row=r, column=c, padx=2, pady=2)
                # Top / Left / Bottom / Right
                top_ch = self._safe_char(self.tb_chars[idx], 0)
                bot_ch = self._safe_char(self.tb_chars[idx], 1)
                left_ch = self._safe_char(self.rl_chars[idx], 0)
                right_ch = self._safe_char(self.rl_chars[idx], 1)

                tp = tk.Label(frame, text=top_ch)
                lf = tk.Label(frame, text=left_ch)
                bt = tk.Label(frame, text=bot_ch)
                rt = tk.Label(frame, text=right_ch)
                tip = tk.Label(frame, text="x", bg=Kb.bk_gr0)

                tp.grid(row=0, column=1)
                lf.grid(row=1, column=0)
                tip.grid(row=1, column=1)
                rt.grid(row=1, column=2)
                bt.grid(row=2, column=1)

                # Save references in a dict
                self.cells.append({
                    'frame': frame,
                    'top': tp,
                    'left': lf,
                    'bottom': bt,
                    'right': rt,
                    'tip': tip,
                })

        # Optionally apply styles passed in
        if 'font' in self.styles:
            for cell in self.cells:
                for key in ('top', 'left', 'bottom', 'right', 'tip'):
                    cell[key].config(font=self.styles['font'])
        if 'active_bg' in self.styles:
            self.active_bg = self.styles['active_bg']
        else:
            self.active_bg = Kb.activ_bg
        if 'active_fg' in self.styles:
            self.active_fg = self.styles['active_fg']
        else:
            self.active_fg = Kb.akitv_text
        self.clear_active()

    def set_active(self, index):
        """Highlight the entire pyramid cell at index (0..rows*cols-1):
        all 4 directional chars + center tip get active colors.
        If index is None or out of range, clear."""
        if 0 <= index < len(self.cells):
            for i, cell in enumerate(self.cells):
                if i == index:
                    # Highlight all 4 directions + tip with active colors
                    for key in ('top', 'left', 'bottom', 'right', 'tip'):
                        cell[key].config(fg=self.active_fg, bg=self.active_bg)
                    cell['tip'].config(text="X")
                else:
                    # Reset to default state
                    for key in ('top', 'left', 'bottom', 'right'):
                        cell[key].config(fg="black", bg=Kb.bk_gr0)
                    cell['tip'].config(text="x", fg="black", bg=Kb.bk_gr0)
        else:
            self.clear_active()

    def clear_active(self):
        """Clear highlighting from all pyramids."""
        for cell in self.cells:
            for key in ('top', 'left', 'bottom', 'right'):
                cell[key].config(fg="black", bg=Kb.bk_gr0)
            cell['tip'].config(text="x", fg="black", bg=Kb.bk_gr0)


class JoystickFrame(tk.Frame):
    """Frame for joystick/modifier indicators. Create once and toggle states via set_left/set_right."""

    def __init__(self, master, labels=None, **styles):
        super().__init__(master)
        labels = labels or Kb.joysticks
        # create labeled grid similar to original j_com
        self.back = tk.Label(self, text=labels[0])
        self.shift1 = tk.Label(self, text=labels[1])
        self.dl = tk.Label(self, text=labels[2])
        self.clrl = tk.Label(self, text=labels[3])
        self.alt = tk.Label(self, text=labels[4])
        self.shift2 = tk.Label(self, text=labels[5])
        self.enter = tk.Label(self, text=labels[6])
        self.blank = tk.Label(self, text=labels[7])

        # grid placement (same positions as original)
        self.back.grid(row=1, column=0)
        self.shift1.grid(row=0, column=1)
        self.dl.grid(row=2, column=1)
        self.clrl.grid(row=1, column=2)
        self.alt.grid(row=1, column=3)
        self.shift2.grid(row=0, column=4)
        self.enter.grid(row=2, column=4)
        self.blank.grid(row=1, column=5)

        # dynamic indicator labels for left/right joystick positions
        # reuse grid positions instead of creating ephemeral labels
        self.left_indicator = tk.Label(self, text="x", bg=Kb.bk_gr0)
        self.right_indicator = tk.Label(self, text="x", bg=Kb.bk_gr0)
        self.left_indicator.grid(row=1, column=1)
        self.right_indicator.grid(row=1, column=4)

    def set_left(self, active=False):
        if active:
            self.left_indicator.config(text="X", fg=Kb.akitv_text, bg=Kb.activ_bg)
        else:
            self.left_indicator.config(text="x", fg="black", bg=Kb.bk_gr0)

    def set_right(self, active=False):
        if active:
            self.right_indicator.config(text="X", fg=Kb.akitv_text, bg=Kb.activ_bg)
        else:
            self.right_indicator.config(text="x", fg="black", bg=Kb.bk_gr0)


class EditorMKPs:
    def __init__(self):
        self.window0 = tk.Tk()
        self.window0.geometry("300x680")
        self.window0.title("pyramid keyboard editor")
        self.text_area = ScrollTxt(self.window0, undo=True)
        self.kb_frame = tk.Frame(self.window0)
        self.joyst_frames = JoystickFrame(self.window0)

        # Layout
        self.text_area.pack(expand=tk.YES, anchor=tk.N, fill='both')
        self.kb_frame.pack(anchor=tk.CENTER)
        self.joyst_frames.pack(anchor=tk.S)

        # Create reusable pyramid keyboard inside kb_frame
        self.pyramid = PyramidKeyboard(self.kb_frame, Kb.rl_ch_e, Kb.tb_ch_e, font=(Kb.font0, 10),
                                       active_bg=Kb.activ_bg, active_fg=Kb.akitv_text)
        self.pyramid.pack()

        # File menu and bindings
        self.create_menu()

        # Bind keys
        self.window0.bind_all("<Return>", self.scan_com_e)
        self.window0.bind_all('<space>', self.scan_com_sp)
        self.window0.bind_all('<Control_L>', self.scan_com_ct)
        self.window0.bind_all('<Alt_L>', self.scan_com_al)
        self.window0.bind_all('<Shift_L>', self.scan_com_sl)
        self.window0.bind_all('<Shift_R>', self.scan_com_sr)
        self.window0.bind_all("<Delete>", self.scan_com_d)
        self.window0.bind_all('<BackSpace>', self.scan_key_bk)
        self.window0.bind_all('<KeyPress>', self.press_key)
        self.window0.bind_all('<KeyRelease>', self.release_key)

        # Start mainloop
        self.start_device_listener()
        self.window0.mainloop()

    # joystick helpers: call joystick frame methods
    def scan_com_e(self, event=None):
        self.joystick_r(1)

    def scan_com_sp(self, event=None):
        self.joystick_r(1)

    def scan_key_bk(self, event=None):
        self.joystick_l(1)

    def scan_com_ct(self, event=None):
        self.joystick_l(1)

    def scan_com_al(self, event=None):
        self.joystick_r(1)

    def scan_com_d(self, event=None):
        self.joystick_l(1)

    def scan_com_sl(self, event=None):
        self.joystick_l(1)

    def scan_com_sr(self, event=None):
        self.joystick_r(1)

    def press_key(self, event=None):
        # Map key char to pyramid index; when found highlight entire pyramid cell.
        ch = event.char if event else ''
        for i in range(15):
            i2 = Kb.ch_e[i]
            if ch and ch in i2:
                self.tip_touch(i)
                break

    def release_key(self, event=None):
        # Non-blocking reset after 500 ms to avoid freezing UI.
        def _reset():
            self.tip_touch(16)  # clear pyramid highlighting
            # Toggle both briefly (original behavior called both)
            self.joystick_r()
            self.joystick_l()

        self.window0.after(500, _reset)

    def kbr(self, x, y):
        # Kept for compatibility if other code calls it; now delegates to PyramidKeyboard
        pass

    def tip_touch(self, x=16):
        """Highlight the entire pyramid cell (all 4 directions + tip) at index x.
        If x >= 15, clear highlighting."""
        if 0 <= x < 15:
            self.pyramid.set_active(x)
        else:
            self.pyramid.clear_active()

    def j_com(self):
        # kept for compatibility; joystick frame is already created
        pass

    def joystick_l(self, x=0):
        self.joyst_frames.set_left(active=(x == 1))

    def joystick_r(self, x=0):
        self.joyst_frames.set_right(active=(x == 1))

    def create_menu(self):
        menu = tk.Menu(self.window0)
        self.window0.config(menu=menu)

        file_menu = tk.Menu(menu, tearoff=0)
        menu.add_cascade(label="File", menu=file_menu)
        file_menu.add_command(label="New", command=self.new_file)
        file_menu.add_command(label="Open", command=self.open_file)
        file_menu.add_command(label="Save", command=self.save_file)
        file_menu.add_separator()
        file_menu.add_command(label="Exit", command=self.window0.quit)

    def new_file(self):
        self.text_area.delete(1.0, tk.END)

    def open_file(self):
        file = filedialog.askopenfilename(defaultextension=".txt",
                                          filetypes=[("Text Files", "*.txt"), ("All Files", "*.*")])
        if file:
            self.window0.title(f"pyramid keyboard editor - {file}")
            self.text_area.delete(1.0, tk.END)
            with open(file, "r", encoding='utf-8') as file_handler:
                self.text_area.insert(tk.INSERT, file_handler.read())

    def save_file(self):
        file = filedialog.asksaveasfilename(defaultextension=".txt",
                                            filetypes=[("Text Files", "*.txt"), ("All Files", "*.*")])
        if file:
            with open(file, "w", encoding='utf-8') as file_handler:
                file_handler.write(self.text_area.get(1.0, tk.END))
            self.window0.title(f"pyramid keyboard editor - {file}")

    def start_device_listener(self):
        """Start listening for external device input (serial/socket)."""
        # Example: serial input on a separate thread
        import threading
        import serial  # or socket, depending on your device
        def listen_device():
            try:
                # Adjust port and baudrate to match your device
                ser = serial.Serial('/dev/ttyUSB0', 9600, timeout=1)
                while True:
                    line = ser.readline()
                    if line:
                        try:
                            value = int(line.decode().strip())
                            # Schedule GUI update on the main thread
                            self.window0.after(0, self.on_device_input, value)
                        except (ValueError, UnicodeDecodeError):
                            pass
            except Exception as e:
                print(f"Device listener error: {e}")

        thread = threading.Thread(target=listen_device, daemon=True)
        thread.start()

    def on_device_input(self, value):
        """Handle incoming device value (0–15)."""
        if 0 <= value <= 14:
            self.tip_touch(value)  # Highlight pyramid cell
        else:
            self.tip_touch(16)  # Clear highlighting


if __name__ == "__main__":
    EditorMKPs()

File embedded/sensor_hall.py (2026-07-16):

# Adafruit CircuitPython 8.2.6 on 2023-09-12; Raspberry Pi Pico with rp2040
# ........................................

"""
Hall effect sensor keyboard controller for Raspberry Pi Pico.

Uses analog hall sensors for top-bottom and left-right movement detection.
A 0.5 second sample interval is used for debugging convenience.
Application window must be activated within a ten-second period to begin text entry.
"""

import asyncio
import board
import analogio
import usb_hid
import time

from adafruit_hid.keyboard import Keyboard
from pk_layout import pyramid_keyboard_layout

# Try to import the touch sensor accessor sens_touch() from sensor_touch.py.
# sens_touch() is expected to return an integer 1..15 for touch addresses or 16 for "no touch".
try:
    from sensor_touch import sens_touch
except Exception as e:
    sens_touch = None
    print("Warning: could not import sens_touch from sensor_touch.py:", e)

# Character mappings for different key positions
TOP_BOTTOM_CHARACTERS = ["'1", "\"2", "(3", "[4", "{5",
                         "$6", "#7", "@8", ";9", "%0",
                         ">+", "<-", "&*", ":/", "!="]
RIGHT_LEFT_CHARACTERS = ["qw", "er", "ty", "ui", "op",
                         "as", "df", "gh", "jk", "l^",
                         "zx", "cv", "bn", "m?", ",."]

# Sensor calibration and thresholds
SENSOR_THRESHOLD = 58500
TB_LABEL = None  # Will be set during autocalibration
LR_LABEL = None  # Will be set during autocalibration
BUFFER_SIZE = 20
SAMPLE_DELAY = 0.5
MIN_MOVEMENT = 100  # Minimum movement to register a key press
CALIBRATION_SAMPLES = 10  # Number of samples to collect during calibration

# Global keyboard device
mkps = Keyboard(usb_hid.devices)

# Async control (can be set from outside to stop loops)
stop_event = asyncio.Event()


class HallBuffer:
    """Buffer for storing sensor readings."""
    
    def __init__(self):
        # initialize buffers with their label sentinel values
        self.tb_hall = [TB_LABEL] if TB_LABEL is not None else []
        self.lr_hall = [LR_LABEL] if LR_LABEL is not None else []
    
    def reset(self):
        """Reset buffers after sending a key."""
        self.tb_hall = [TB_LABEL] if TB_LABEL is not None else []
        self.lr_hall = [LR_LABEL] if LR_LABEL is not None else []


async def autocalibrate_sensors():
    """
    Autocalibrate Hall sensors at startup.
    Waits for no-touch condition (sens_touch() == 16) and then collects
    CALIBRATION_SAMPLES readings from both sensors to establish baseline values.
    
    Returns:
        tuple: (TB_LABEL, LR_LABEL) calibrated values
    """
    global TB_LABEL, LR_LABEL
    
    print("Starting sensor autocalibration...")
    print("Please ensure no keys are being touched.")
    
    if sens_touch is None:
        print("Error: sens_touch unavailable; cannot autocalibrate. Using default values.")
        TB_LABEL = 58501
        LR_LABEL = 58502
        return TB_LABEL, LR_LABEL
    
    # Wait for no-touch condition
    max_wait_attempts = 50  # ~25 seconds at 0.5s per check
    wait_attempts = 0
    
    while wait_attempts < max_wait_attempts:
        try:
            x = sens_touch()
            if x == 16:  # No touch detected
                print("No-touch condition detected. Beginning calibration...")
                break
        except Exception as e:
            print("Error reading touch sensor during wait:", e)
        
        await asyncio.sleep(0.5)
        wait_attempts += 1
    else:
        print("Warning: Timeout waiting for no-touch condition. Proceeding anyway.")
    
    # Collect calibration samples
    tb_samples = []
    lr_samples = []
    
    print(f"Collecting {CALIBRATION_SAMPLES} calibration samples...")
    
    try:
        with analogio.AnalogIn(board.A0) as pin_tb, analogio.AnalogIn(board.A1) as pin_lr:
            for i in range(CALIBRATION_SAMPLES):
                tb_samples.append(pin_tb.value)
                lr_samples.append(pin_lr.value)
                print(f"Sample {i+1}: TB={pin_tb.value}, LR={pin_lr.value}")
                await asyncio.sleep(SAMPLE_DELAY)
    except Exception as e:
        print("Error during sensor calibration:", e)
        TB_LABEL = 58501
        LR_LABEL = 58502
        return TB_LABEL, LR_LABEL
    
    # Calculate average values
    TB_LABEL = sum(tb_samples) // len(tb_samples)
    LR_LABEL = sum(lr_samples) // len(lr_samples)
    
    print(f"Calibration complete!")
    print(f"TB_LABEL (board.A0) = {TB_LABEL}")
    print(f"LR_LABEL (board.A1) = {LR_LABEL}")
    
    return TB_LABEL, LR_LABEL


def send_key(character):
    """
    Send keyboard key based on character.
    
    Args:
        character: single-character string from the keyboard layout mapping
    """
    if character not in pyramid_keyboard_layout:
        print("Character not in layout:", repr(character))
        return
    
    key_code = pyramid_keyboard_layout[character]
    
    if isinstance(key_code, tuple):
        mkps.send(key_code[0], key_code[1])
    else:
        mkps.send(key_code)
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

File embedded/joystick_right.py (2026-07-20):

"""Read PWM X/Y from a right-hand joystick (GP10/GP11) and send mapped keyboard HID commands while the joystick is touched."""

import time
import math
import board
import pulseio
import usb_hid
from adafruit_hid.keyboard import Keyboard

# import keyboard layout and touch sensor module (if available)
from pk_layout import pyramid_keyboard_layout

try:
    import sensor_touch as st  # module provides mpr121 and sens_touch()
    sens_touch = st.sens_touch
except Exception as e:
    st = None
    sens_touch = None
    print("Warning: could not import sensor_touch module:", e)

# Logical command mapping for clock sectors
control_command_clock = {'12': 'Shift', '3': '->', '6': 'Enter', '9': 'Alt'}

# Pin settings: X - sensor A, Y - sensor B
pin_x = board.GP10
pin_y = board.GP11

pulse_x = pulseio.PulseIn(pin_x, maxlen=2)
pulse_y = pulseio.PulseIn(pin_y, maxlen=2)

# Electrode and sens_touch code mapping (adjust indices/codes to match your hardware)
# These constants make which electrode corresponds to which joystick explicit and
# avoid "8 vs 9" style inconsistencies throughout the file.
JOYSTICK_RIGHT_ELE = 9            # mpr121 index for the right joystick touch electrode
JOYSTICK_LEFT_ELE = 8             # other joystick electrode index (used when checking both)
JOYSTICK_TOUCH_CODE = 18          # sens_touch() return code that indicates joystick touch/start
STOP_TOUCH_CODE = 19              # sens_touch() return code that indicates stop/exit

# --- CALIBRATION SETTINGS ---
# Run the code, look at the actual percentages in the console at the extremes
# and enter your own values in place of these templates (currently set to 10%-90% with center 50%):
X_MIN, X_CENTER, X_MAX = 10.0, 50.0, 90.0
Y_MIN, Y_CENTER, Y_MAX = 10.0, 50.0, 90.0

DEADZONE = 5.0  # Deadzone in % (ignores small noises around the center)

keyboard = Keyboard(usb_hid.devices)


def get_duty_cycle(pulse_obj):
    """Read PWM duty cycle (%) from pulseio.PulseIn object.

    pulse_obj contains alternating high, low durations; use first two samples.
    """
    if len(pulse_obj) >= 2:
        high = pulse_obj[0]
        low = pulse_obj[1]
        total = high + low
        if total > 0:
            return (high / total) * 100.0
    return None


def map_axis(current_val, axis_min, axis_center, axis_max):
    """Convert PWM percentage to -100..+100 range taking calibration center into account."""
    if current_val is None:
        return 0.0

    current_val = max(axis_min, min(axis_max, current_val))

    if current_val < axis_center:
        raw_val = ((current_val - axis_center) / (axis_center - axis_min)) * 100.0
    else:
        raw_val = ((current_val - axis_center) / (axis_max - axis_center)) * 100.0

    if abs(raw_val) < DEADZONE:
        return 0.0

    return raw_val


def angle_from_xy(x, y):
    """Return angle in degrees [0, 360) with 0 at +X (3 o'clock), increasing CCW."""
    deg = math.degrees(math.atan2(y, x))
    deg = (deg + 360.0) % 360.0
    return deg


def joystick_sector(joy_x, joy_y):
    """Map joystick (x,y) to one of the clock sectors '12','3','6','9' or None.

    Sector centers (degrees): 3 -> 0°, 12 -> 90°, 9 -> 180°, 6 -> 270°
    Tolerance: ±30° (one-hour tolerance)
    """
    # if near center, treat as no sector
    if abs(joy_x) < 15.0 and abs(joy_y) < 15.0:
        return None

    deg = angle_from_xy(joy_x, joy_y)

    # Define ranges (inclusive). Handle wrap-around for 3 o'clock.
    if (deg >= 330.0 or deg <= 30.0):
        return '3'
    if 60.0 <= deg <= 120.0:
        return '12'
    if 150.0 <= deg <= 210.0:
        return '9'
    if 240.0 <= deg <= 300.0:
        return '6'
    return None


def send_key_for_clock(clock_label):
    """Lookup command via control_command_clock -> pyramid_keyboard_layout -> send via USB HID."""
    cmd_label = control_command_clock.get(clock_label)
    if cmd_label is None:
        print("No command mapped for clock", clock_label)
        return

    keycodes = pyramid_keyboard_layout.get(cmd_label)
    if keycodes is None:
        print("No keycodes in layout for command", cmd_label)
        return

    # keycodes may be a single Keycode or a tuple of Keycodes
    if isinstance(keycodes, tuple) or isinstance(keycodes, list):
        keyboard.send(*keycodes)
    else:
        keyboard.send(keycodes)

    print(f"Sent command '{cmd_label}' for clock {clock_label}")


def joystick_touch_active():
    """Return True if right joystick (JOYSTICK_RIGHT_ELE) is currently touched using mpr121, if available.

    Fallback: if sensor_touch module is not available, return True (can't detect).
    """
    if st is None:
        # No direct sensor module available; fallback to True so joystick logic can run
        return True

    try:
        # mpr121[JOYSTICK_RIGHT_ELE] corresponds to the right joystick touch electrode
        return bool(st.mpr121[JOYSTICK_RIGHT_ELE].value)
    except Exception as e:
        print("Error reading mpr121 directly:", e)
        return False


print("Waiting for right joystick touch (sensor value 18) to activate...")
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

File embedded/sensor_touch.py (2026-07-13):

# Adafruit CircuitPython 8.2.6 on 2023-09-12; Raspberry Pi Pico with rp204
# I used a sensor matrix circuit using diodes; it seems that few people have done this before me.
import time
import board
import busio
import adafruit_mpr121

i2c = busio.I2C(board.GP5, board.GP4)
mpr121 = adafruit_mpr121.MPR121(i2c)

# Map of xy coordinate strings to pyramid key numbers (1-15)
# y (rows): 0-2, x (columns): 3-7
map_touch_pyramid = {"03":1, "04":2, "05":3, "06":4, "07":5,
                     "13":6, "14":7, "15":8, "16":9, "17":10,
                     "23":11, "24":12, "25":13, "26":14, "27":15}

def sens_touch():
    """
    Read touch sensor input from pyramid keyboard matrix and joysticks.
    
    Pyramid keyboard (ELE0-ELE7):
      - Polls 8 pins arranged as 3 rows × 5 columns
      - Returns key number (1-15) when pyramid touched, or 16 (no-touch) on timeout
    
    Joysticks (ELE8-ELE9):
      - ELE8 (joystick 1) returns 17 when touched
      - ELE9 (joystick 2) returns 18 when touched
      - Both joysticks touched returns [17, 18]
      - No joystick touched returns 19
    
    Complex combinations:
      - Pyramid + joystick(s) simultaneously: returns pyramid key (1-15) and joystick value(s)
        as a list, e.g., [7, 17] for pyramid key 7 + joystick 1
    """
    previous_pyramid_pressed = None
    previous_joystick_state = set()
    timeout_counter = 0
    
    while True:
        pressed_now = None
        
        # ==================== PYRAMID KEYBOARD POLLING ====================
        # Poll pyramid sensors (ELE0-ELE7)
        # Rows: pins 0-2 (y-axis)
        # Columns: pins 3-7 (x-axis)
        row_pin = None
        col_pin = None
        
        # Check rows (pins 0-2)
        for i in range(3):
            if mpr121[i].value:
                row_pin = i
                break
        
        # Check columns (pins 3-7, for 5 columns)
        for i in range(3, 8):
            if mpr121[i].value:
                col_pin = i
                break
        
        # If both row and column are pressed, we have a valid pyramid touch
        if row_pin is not None and col_pin is not None:
            pressed_now = f"{row_pin}{col_pin}"
        
        # ==================== JOYSTICK POLLING ====================
        # Poll joystick pins (ELE8 and ELE9)
        joystick_pressed = set()
        
        if mpr121[8].value:
            joystick_pressed.add(17)
        
        if mpr121[9].value:
            joystick_pressed.add(18)
        
        # ==================== PROCESS PYRAMID STATE CHANGE ====================
        if pressed_now != previous_pyramid_pressed:
            if pressed_now is not None:
                # Pyramid was just touched
                if pressed_now in map_touch_pyramid:
                    key_num = map_touch_pyramid[pressed_now]
                    
                    # Check if joystick(s) are also pressed
                    if joystick_pressed:
                        result = [key_num] + sorted(list(joystick_pressed))
                        print(f"Complex combination: Pyramid {pressed_now} (Key {key_num}) + Joysticks {joystick_pressed} → {result}")
                        return result
                    else:
                        print(f"Pyramid touched: {pressed_now} → Key {key_num}")
                        return key_num
                else:
                    print(f"Invalid pyramid coordinate: {pressed_now}")
                
                timeout_counter = 0  # Reset on valid touch
            
            previous_pyramid_pressed = pressed_now
        
        # ==================== PROCESS JOYSTICK STATE CHANGE ====================
        if joystick_pressed != previous_joystick_state:
            if joystick_pressed:
                # Joystick(s) just pressed (only if pyramid not pressed)
                if pressed_now is None:
                    result = sorted(list(joystick_pressed))
                    if len(result) == 1:
                        print(f"Joystick touched: {result[0]}")
                        return result[0]
                    else:
                        print(f"Both joysticks touched: {result}")
                        return result
            else:
                # Both joysticks just released (only if pyramid not pressed)
                if pressed_now is None and previous_pyramid_pressed is None:
                    print("Timeout: no touch detected, returning 16 (keyboard no-touch)")
                    return 16
            
            previous_joystick_state = joystick_pressed
        else:
            # No state change—increment timeout if nothing pressed anywhere
            if pressed_now is None and not joystick_pressed:
                timeout_counter += 1
                if timeout_counter > 50:  # Adjust threshold as needed
                    print("Timeout: no touch detected, returning 16 (keyboard no-touch)")
                    return 16  # Return 16 as the keyboard no-touch value
        
        time.sleep(0.1)  # Debounce delay

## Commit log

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2019-10-12 short send 1,1 cut
2019-10-12 short send 1,1 cut + send
2023-03-26 cap and touch
    [cap_in3.FCStd, touch_bottom1.FCStd]
2023-03-26 sensor details
    [cap_out3.FCStd, conn_cap2.FCStd, hinge_rods3.FCStd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]
2023-03-27 new parts and asm
    [buffer.FCStd, fix_ring_left.FCStd, fix_ring_rght.FCStd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]
2023-03-27 main rod
    [main_rod_arm.FCStd, rod shell top.FCStd, rod_shell_btm.FCStd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]
2023-03-28 button mechanism
    [button_mechanism.FCStd, mouse_button_left.FCStd, mouse_button_right.FCStd]
2023-03-29 sliding mesh and joystic
    [fixing_pin.FCStd, magnet.FCStd, magnet_holder.FCStd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]
2023-03-30 keyboard module
    [keyboard_module.FCStd, main module.FCStd, mov_joystick_block.FCStd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]
2023-03-31 bottom and walls
    [battery_wall_right.FCStd, back_cover.FCStd, back_lock.FCStd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]
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2023-04-01 fin adding part files
    [Raspberry_pi_Pico.FCStd, axle_tube_case.FCStd, button_mechanism.FCStd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]
2023-04-01 main module
    [main module.FCStd]
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2023-04-13 fix error hall
    [motherboard.kicad_pcb, motherboard.kicad_sch]
2023-04-24 led board
    [LED Board.kicad_pcb, LED Board.kicad_sch, led_board.FCStd]
2023-04-24 led fix error
    [LED Board.kicad_pcb, led_board.FCStd, top_keyboard.FCStd]
2023-04-25 led pyramid module
    [keyboard_module.FCStd, top_keyboard_led.FCStd]
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2023-05-01 conn plug battery
    [batr_conn_min.FCStd, batr_conn_pls.FCStd, plug_back.FCStd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]
2023-05-06 fix plug battr
    [batr_conn_min.FCStd, batr_conn_pls.FCStd, plug_back.FCStd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]
2023-05-07 delet rings
    [battery_wall_right.FCStd, battery_wall_left.FCStd, button_mechanism.FCStd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]
2023-05-08 ,attry connectors
    [conn_btr_asm.FCStd, pin_conn_btr.FCStd, pin_conn_btr2.FCStd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]
2023-05-17 side pcb
    [battery_wall_left.FCStd, battery_wall_left_asm.FCStd, left side PCB.kicad_pcb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]
2023-05-17 battery wall r asm
    [battery_wall_right.FCStd, battery_wall_right_asm.FCStd, right side PCB.kicad_pcb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]
2023-05-19 middle connect
    [battery_wall_right.FCStd, battery_wall_left.FCStd, battery_wall_left_asm.FCStd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]
2023-05-24 conn in mother 5
    [battery_wall_left_asm.FCStd, left side PCB.kicad_pcb, left side PCB.kicad_sch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]
2023-05-25 right conn mother
    [battery_wall_right_asm.FCStd, right side PCB.kicad_pcb, right side PCB.kicad_sch]
2023-05-30 conn side led
    [LED Board.kicad_pcb, side_led_conn.FCStd, top_keyboard_led.FCStd]
2023-06-10 add led conn pcb
    [battery_wall_left_asm.FCStd, battery_wall_right_asm.FCStd, left side PCB.kicad_pcb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]
2023-06-12 correct conn led
    [battery_wall_left_asm.FCStd, battery_wall_right_asm.FCStd, left side PCB.kicad_pcb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]
2023-06-16 motherboard conn
    [motherboard.kicad_pcb, motherboard.kicad_sch, mouse_microcontroller.kicad_sch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]
2023-06-22 power end
    [motherboard.kicad_pcb, motherboard.kicad_sch, mouse_microcontroller.kicad_sch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]
2023-07-04 new sensor
    [touch_bottom1.FCStd, touch_bottom1.step, touch_bottom1.stl]
2023-07-13 grill sockt
    [buffer3_spring.FCStd, mov_joystick_block.FCStd, mov_kb_block.FCStd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]
2023-07-16 new asm sns
    [button_mechanism.FCStd, keyboard_module.FCStd, main module.FCStd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]
2023-07-17 wall left right
    [battery_wall_left_asm.FCStd, battery_wall_right_asm.FCStd]
2023-07-24 mkp new
    [LED Board.kicad_pcb, button_mechanism.FCStd, keyboard_module.FCStd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]
2023-07-24 bom dell1
    [bom.xlsx, cap_in3.FCStd]
2023-07-25 mkp2 del8
    [buffer.FCStd, bottom_mezz_conn.FCStd, cap_out3.FCStd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]
2023-07-31 cap nich
    [keyboard_module.FCStd, main module.FCStd, motherboard.kicad_pcb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]
2023-08-03 top lock
    [battery_wall_right.FCStd, back_lock.FCStd, battery_wall_left.FCStd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]
2023-08-03 cjver stock
    [back_cover.FCStd, back_cover_stock.FCStd, stock.FCStd]
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2023-08-21 screen keyboard
    [back_cover.FCStd, back_cover_stock.FCStd]
2023-08-25 delrt tree md bom
    [bom.xlsx]
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2023-11-16 cp10 to A0
    [motherboard.kicad_pcb, motherboard.kicad_sch, mouse_microcontroller.kicad_sch]
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2023-12-05 magnet holders
    [keyboard_module.FCStd, magnet_holder.FCStd, magnet_with_holder.FCStd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]
2023-12-12 bom new
    [bom.xlsx, buffer3_spring.FCStd, keyboard_module.FCStd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]
2023-12-21 spring clcpw
    [buffer_spring_asm.FCStd, hinge_rods3.FCStd, keyboard_module.FCStd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]
2023-12-22 bom add
    [bom.xlsx]
2024-05-10 new branch
    [buffer5_spring.FCStd]
2024-05-12 spring x
    [buffer5_spring.FCStd]
2024-05-13 spring asm
    [buffer5_spring.FCStd, buffer_spring_asm.FCStd, hinge_rods3.FCStd]
2024-05-27 top spring
    [battery_wall_left_asm.FCStd, battery_wall_right_asm.FCStd, button_mechanism.FCStd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]
2024-06-18 kikad te
    [motherboard.kicad_pcb, motherboard.kicad_sch, mouse_microcontroller.kicad_sch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]
2024-11-11 red plugin
    [bom.xlsx, joyst_set.FCStd, kb_set.FCStd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]
2026-07-04 page branch
    [f_plan03072026.xlsx]
2026-07-13 Add joystick polling to sensor_touch.py
    - Poll joysticks on ELE8 and ELE9 (return values 17, 18)
    - Return 17 for joystick 1 touch, 18 for joystick 2 touch
    - Return both [17, 18] when both joysticks touched simultaneously
    - Support complex combinations: pyramid + joystick(s) as list (e.g., [7, 17])
    - Keep keyboard no-touch as 16, joystick-only no-touch returns 16 as well
    - Separate state tracking for pyramid and joysticks
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2026-07-16 Add autocalibration for Hall sensors at startup
    - TB_LABEL and LR_LABEL are now initialized to None
    - Added autocalibrate_sensors() function that:
    - Waits for no-touch condition (sens_touch() == 16)
    - Collects CALIBRATION_SAMPLES readings from both sensors
    - Computes average values as calibration baselines
    - Sets global TB_LABEL and LR_LABEL variables
    - Includes fallback to default values if calibration fails
    - Updated main() to call autocalibrate_sensors() at startup
    - Updated HallBuffer to handle None label values
    - Added CALIBRATION_SAMPLES constant (default: 10 samples)
    [sensor_hall.py]
2026-07-17 Add mouse button and encoder inputs, replace CS with USB HID mouse
    [PMW3360.py]
2026-07-19 Update joystick_left.py: track left joystick while touched; map 4 clock sectors and send HID keycodes
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2026-07-22 Revert "code_plagin_hid"
    This reverts commit 6e8c003effeee7340690730b63bf4945da410ebb.
    [code.py]
